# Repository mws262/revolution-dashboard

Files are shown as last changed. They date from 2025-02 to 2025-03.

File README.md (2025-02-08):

A dashboard based on a Lilygo T-Display S3 Touch

 Compatible with VESC firmware 6.02

Dashboard features:
- Show the Battery level and voltage
- Velocity, Trip, ESC and Motor temp
- WiFi connection, OTA programming
- Switching the headlight
- control Rear light & Brake light 
- two driving modes

More information in the Documentation.pdf

Link to 3d printfiles: https://www.thingiverse.com/thing:6682820

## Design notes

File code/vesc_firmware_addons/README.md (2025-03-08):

# Optional adjustments to VESC firmware
My motor controller is an FT85BD. I converted it from using Flipsky's proprietary hardware (see https://github.com/mws262/flipsky-ft85bd-vesc). It has its own MOSFETs for controlling accessories like brake lights and headlight. 

The app_lights VESC application can listen for these commands and switch accordingly. For now, the app is directly started in main.c. In the Rev code, there is a flag, VESC_CONTROLS_LIGHTS, that when set tells the VESC to turn the lights on instead of using ESP32 digital pins to switch the FETs directly.

Note that for the FT85BD, the outputs for the lights are 12V. On the Rev, I believe the lights are 5V. 12V will definitely fry the rear lights. My Rev is missing a bunch of parts, so I don't know about the stock front lights.

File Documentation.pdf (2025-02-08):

# Photo: Levi Jacob Price Rebuilding the Boosted Rev

Documentation

Roland Stollnberger
stollnberger@gmx.at
10.10.2024

Disclaimer
The steps and procedures described in this guide for replacing the electrical components of an e-scooter are intended only for experienced and knowledgeable individuals. Replacing and using modified electrical components can be dangerous and requires a high level of technical understanding and craftsmanship.
Important Notes:
Legal Regulations: Please observe local laws and regulations regarding modifying or the use of modified e-scooters on public roads. Disclaimer: The author of this guide assumes no liability for damages or injuries resulting from the replacement or use of the described electrical components or the provided code. All information is provided without warranty.
Electrical Safety: Handling electrical components can be dangerous. Replacing and using modified electrical components is at your own risk. Ensure that all electrical connections are properly insulated and secured to avoid short circuits and electric shocks.

By using this guide, you agree to the above terms and confirm that you understand the risks.

Unfortunately, a simple battery replacement is not possible with the Rev because the communication between the battery's BMS and the controller has not been cracked yet. The original controller does not start when a retrofit BMS is connected.
To bring the Rev back to live and enhance the range it is necessary to replace the controller, the battery and the dashboard.
There is no plug & play solution. Three main steps are necessary to rebuild the Rev:
- Build a dashboard, in this case with a Lilygo T-Display S3 Touch
- Make a 12s5p Battery
- Buy a VESC based Controller - the Lacroix Stormcore D60+ was used here
(Lacroix went out of business, but there are some alternatives like the VESC HD-60T)

All necessary Files are provided here:
https://github.com/stolliroli/revolution-dashboard

### Step 1 - Dashboard

Part list:
Lilygo T-Display S3 Touch | https://www.lilygo.cc/products/t-display-s3?variant=42589373268149
PCB | https://aisler.net/stolliroli/rolis-projects/revolution-dashboard
| Or use any other fabricator, the files are located in the provided link above.
2x AQV252G PhotoMOS
2x 220 Ohm Resistor, 0805 SMD
1x 1 kOhm Resistor, 0805 SMD
1x 12mm Momentary Switch (short version)
2,54mm JST-XH connector (3x 2Pin, 2x 3Pin, 1x 4Pin) It's best to get a set 3D printed parts (PETG or any other outdoor suitable filament)
Some 2mm screws
2.54mm 2x 12 Pin Female socket Board
Thin wire
4x M3 brass thread inserts

The easiest way to write the code to the Lilygo is using the Arduino IDE.
Following the instruction on Github https://github.com/Xinyuan-LilyGO/T-Display-S3 will help to install the libraries and do the correct settings for the Lilygo display.
Further instructions are in the code “Revolution_Dashboard_1.0.ino” of the shared link.

Once the code is opened in Arduino IDE, there are some settings to check in the Config.h tab (Step 6 – Dashboard config). To program the board later over WIFI it is important to provide your WIFI SSID and Password before installing the Lilygo in the housing. After installation it becomes difficult to connect USB. When the code has been uploaded, next time the Lilygo is connected to USB Power and any of the unlock codes (for driving modes) has been typed in, “WIFI connected” will appear below the battery bar.
Now the port settings have to be changed in Arduino IDE to the IP address of your Lilygo to test the OTA programming.

PCB assembly:

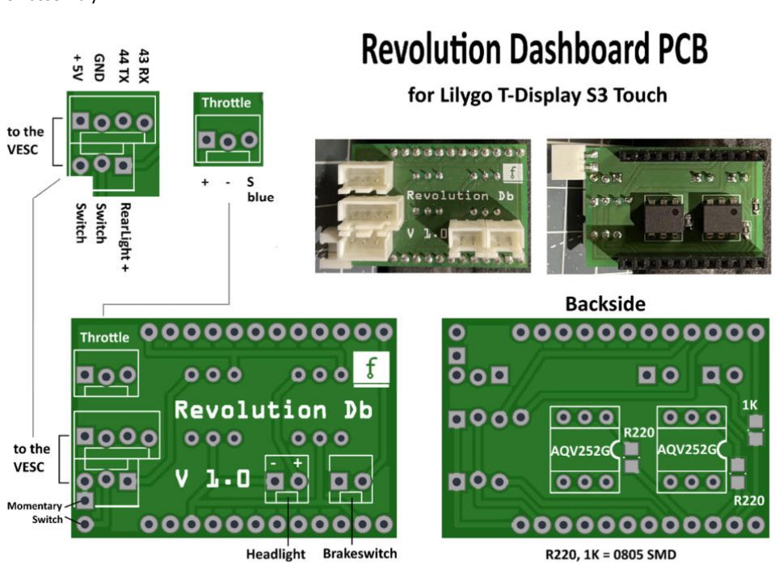
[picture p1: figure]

Before assembly, the housing can be coated with matt clear varnish to make it waterproof.

The Lilygo display is attached with the bracket and two 2mm flat head screws. None of the SMD components should get pinched (If the Lilygo board layout has been changed). Now the PCB can be attached to the Lilygo Display.

Note the following steps if you want to seal the display.
I used “Kafuter K-586 Black Silicone Free Gasket” to seal the display.
First, cover the display with thin plastic packaging tape and insert it into the housing.
Using a craft knife to careful cut along the display recess in the housing. Don't worry, the display glass is so hard and won't get any scratches.
Remove the display again and peel off the tape around the display.
Also cover the housing with the packaging tape and carefully cut out the recess for the display.
Apply the sealant to the inside edge where the display will later rest.
After attaching the display, excess sealing can be wiped off and the packaging tape removed. Allow the seal to cure overnight.

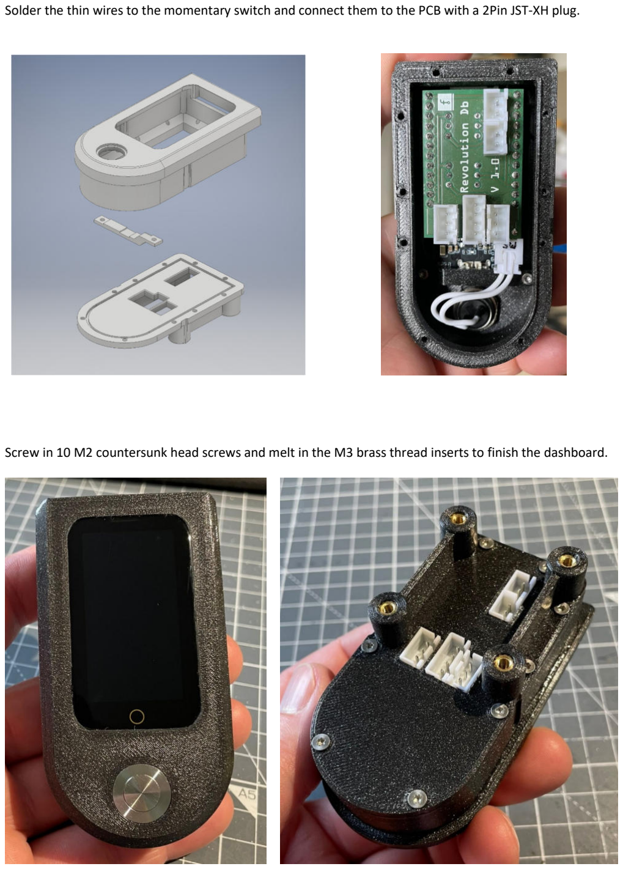
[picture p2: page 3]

Solder the thin wires to the momentary switch and connect them to the PCB with a 2Pin JST-XH plug.

Screw in 10 M2 countersunk head screws and melt in the M3 brass thread inserts to finish the dashboard.

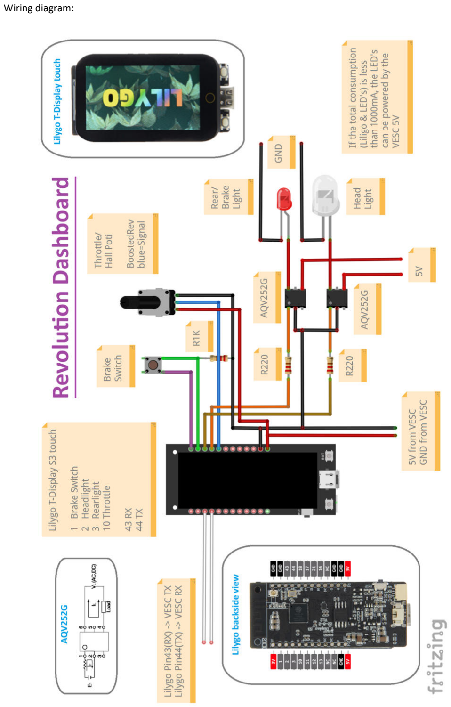
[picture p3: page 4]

Wiring diagram:

### Step 2 - Battery build

Part list:
60x INR21700-P42A https://www.nkon.nl/de/molicel-21700a-4200mah-30a.html JBD Bluetooth Smart BMS 10S-17S 50A
| https://www.aliexpress.com/item/1005005997653586.html?spm=a2g0o.order_list.
| order_list_main.67.34b61802zEt qc9
pure nickel strips (take a look at the chart below)

### 10 AWG Silicon Wire red/black ~30cm (main cable) 16 AWG Silicon Wire red/black ~1m (charging cable) 14 AWG Silicon Wire ~12cm (bus bar)

XT90 female connector (to Stormcore)
XT30 connector pair (charging cable)
60x Cell insulator rings (gasket paper) for 21700 cells Battery Insulation Gasket Barley Paper
Kapton tape 50mm
Shrink tube 180mm x 1m

Keep in mind that your new setup will draw up to 40-50 Ampere. But not all spot welders are able to weld 0.3mm nickel stripes. Multiply the amperage in the table by the number of cells connected in parallel to determine your requirements. Example: 9,6A (0,2mm) x 5 (Cells) = 48A
You can use wider stripes as well. It depends on what you want to do with your Rev.
My measurement was max. 40 Amps on the original Rev ESC.

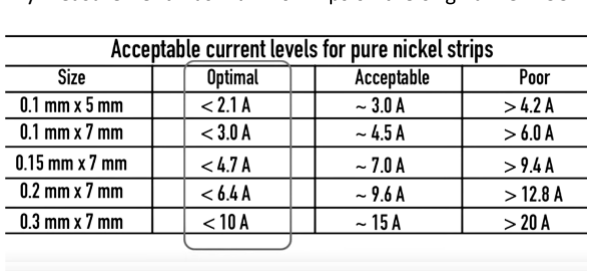
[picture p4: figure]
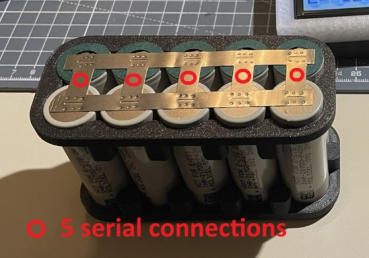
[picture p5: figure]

In order to build a good battery, it is important to test the cells. Faulty cells affect battery performance and lifespan. Many tests can take a lot of time. You should at least check the internal resistance of the individual cells. Outliers should be eliminated. The YR1035+ would be a good choice for this task. Furthermore, it is very important that the cells have the same voltage before welding the cells in parallel to avoid excessive compensating currents.
Calculation: Ampere = V diff / (mOhm/1000). 1-2 A will be OK.
For balancing the cells you need a charger. My V diff was below 0,01V.

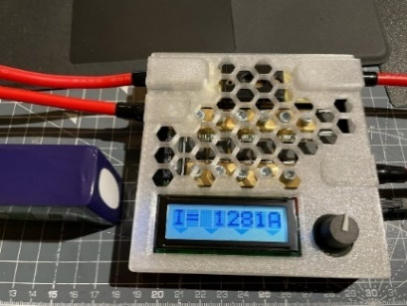
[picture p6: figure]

After a lot of research, I decided on the kWeld spot welder. It draws 1280 Ampere per weld.
This thing rocks.
https://www.keenlab.de/index.php/product/kweld-complete-kit/

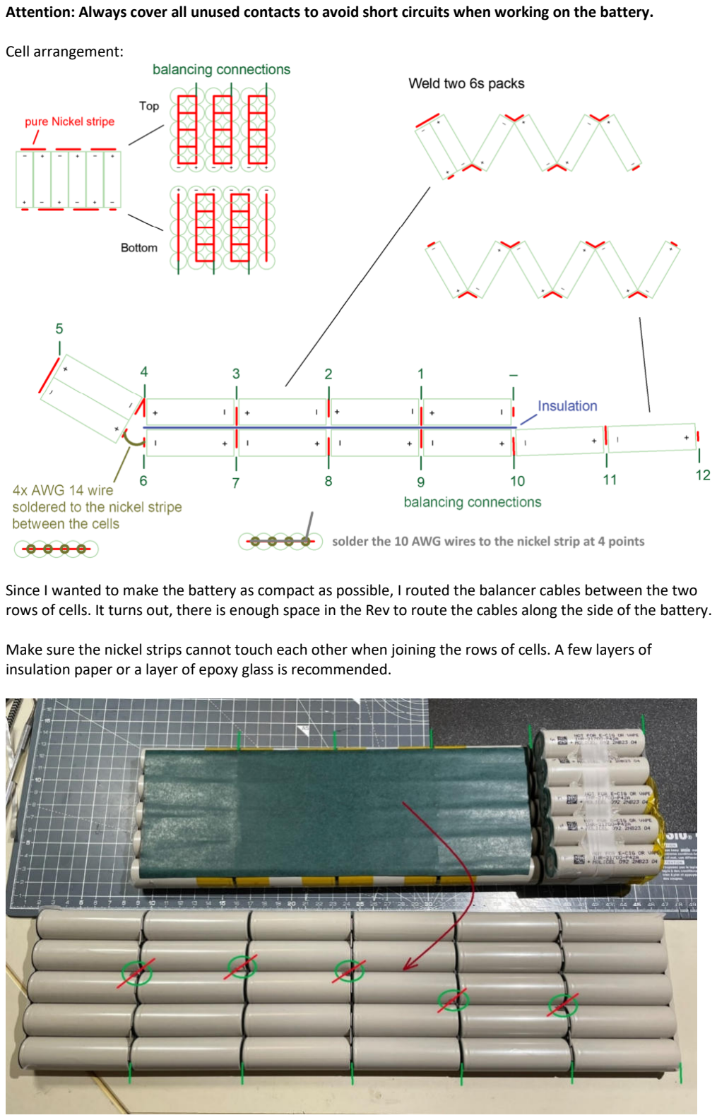
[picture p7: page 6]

Attention: Always cover all unused contacts to avoid short circuits when working on the battery.

Cell arrangement:

Since I wanted to make the battery as compact as possible, I routed the balancer cables between the two rows of cells. It turns out, there is enough space in the Rev to route the cables along the side of the battery.

Make sure the nickel strips cannot touch each other when joining the rows of cells. A few layers of insulation paper or a layer of epoxy glass is recommended.

Remove the plug from the BMS first to solder the BMS cables to the battery. This must be connected later.

The BMS can handle 17 cells in serial. Since we are building a 12s battery, the balancer cables 11-16 must be connected together to the battery connection 11. The 17th cable is connected to cell 12.

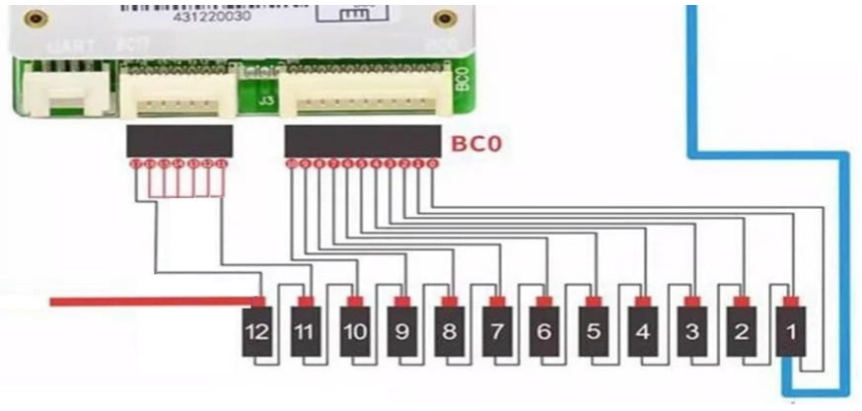
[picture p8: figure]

Building this battery is a bit difficult because the floor inside the Rev is not flat.
To avoid puncturing the battery, I glued foam rubber to important places. Make sure that the battery does not press on the screws of the skid plates.

Before wrapping the battery in insulation paper, I taped off all the contacts and placed the battery in the Rev to measure the angles of the bends. To do this I used a small electronic protractor. Then I recreated the angles on the workbench using wedges. Once the insulation paper is glued to the battery (start with the side walls first), the shape is maintained and the battery should fit into the Rev.

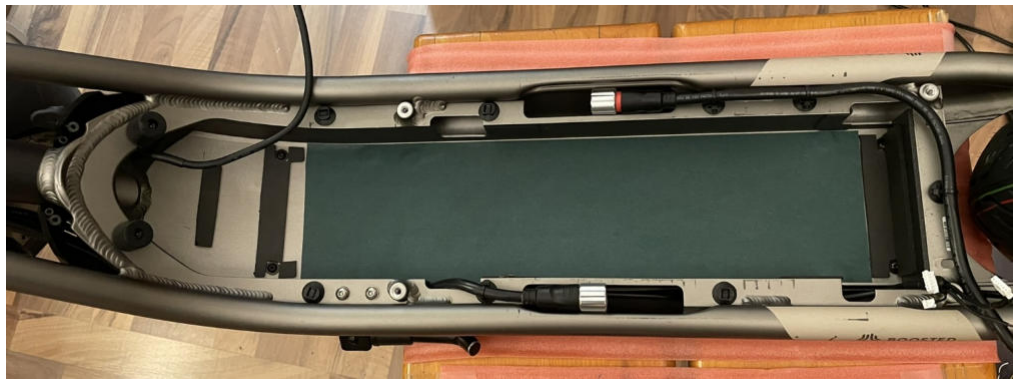
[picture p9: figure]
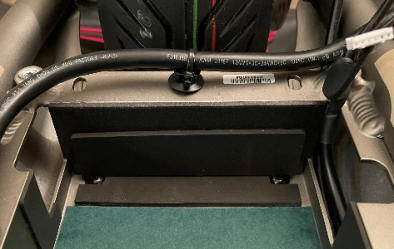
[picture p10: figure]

My Rev doesn't need to be waterproof, but I wanted to keep most of the dust out. That's why I used a 3D printed plate at the back and closed the holes at the floor.
Later I closed the front and rear openings of the side channels with foam rubber.

The BMS has been attached with double-sided adhesive tape to the battery. To avoid heat problems, it is recommended to insert a sheet of epoxy glass in between. Connect the main cables and the charging cable and also the temperature sensors. The final step is to connect the BMS cables and setup the BMS.
Attach the shrink tubing.

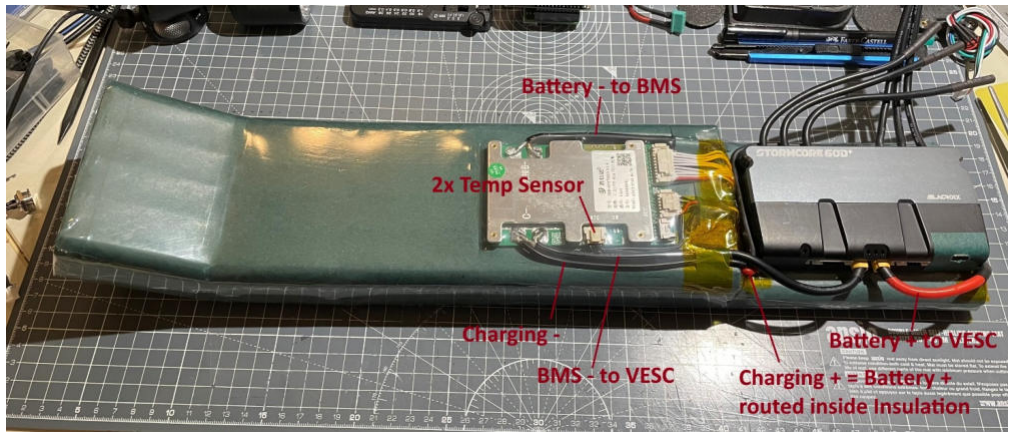
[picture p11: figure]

I taped the ESC on top of the lower cell-row. The ESC could reach higher temperature. A sheet of epoxy glass and thicker double-sided tape is recommended to get a bit of air circulation.

### Step 3 – Setup the BMS

The output and charging function were turned off as default at my JBD BMS. To setup the BMS download the smartphone app. There will be a recommendation from the seller for the associated app to use.
In my case I installed the XiaoXiang iOS app.
You must create a user account to have fully access to the software. Otherwise you can only view data but not change any settings.

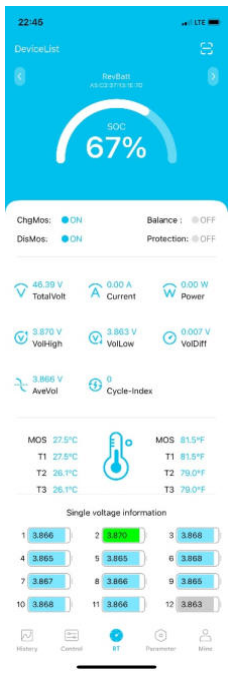
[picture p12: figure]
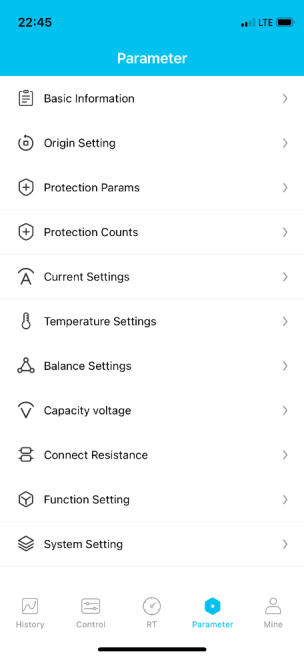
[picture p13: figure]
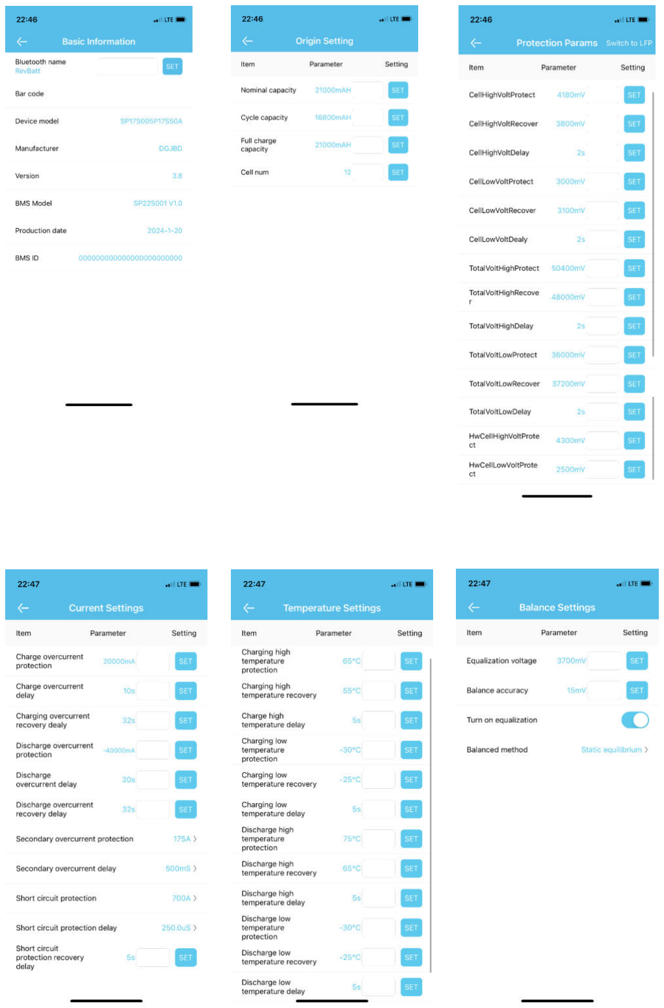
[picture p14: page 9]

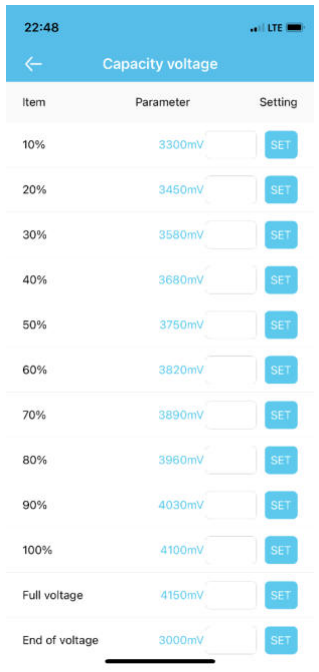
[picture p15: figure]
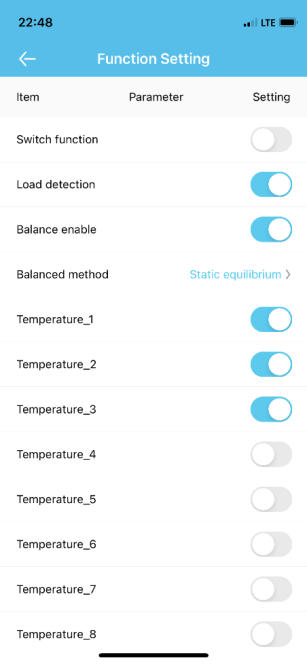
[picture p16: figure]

The BMS should show 12 cells if it is connected correctly to the battery.
Take care about the protection parameters.

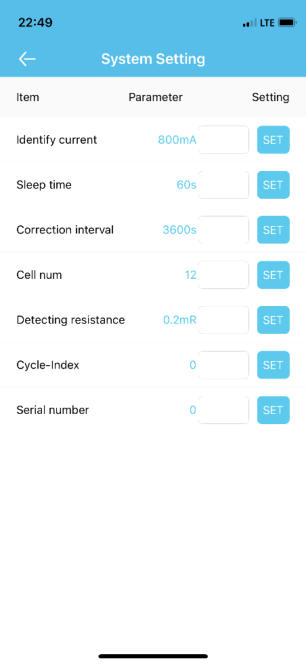
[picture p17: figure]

Unfortunately I couldn't find any instructions for this specific BMS. In the instructions for a similar BMS, at least the principle is well explained: https://macsbatteries.com/images/bms_manuals/Xiaoxiang_BMS_Manual-20220714.pdf

### Step 4 – put it together

Part list:
VESC based Controller
Cable 24AWG, 7Cores, 2m
2,54mm JST-XH connector (3x 2Pin, 2x 3Pin, 1x 4Pin)
2.00mm JST-PH connector (for connecting the Stormcore, other ESC may have other connectors) 6x 4mm Gold Bullet Connector Female
XT30 connector pair (charging cable)

To strip out the original Data cable, gently pull out the two rubber sealings on the steering stem. Build a new Data cable from the Dashboard to the VESC and put it into
the stem.
Ad one 3 Pin and one 4 Pin JST-XH Plug to the cable to connect the
dashboard.

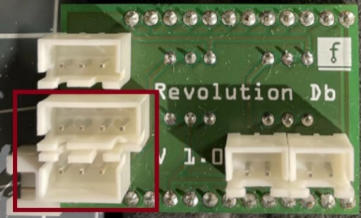
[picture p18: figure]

Connection diagram Stormcore D60+

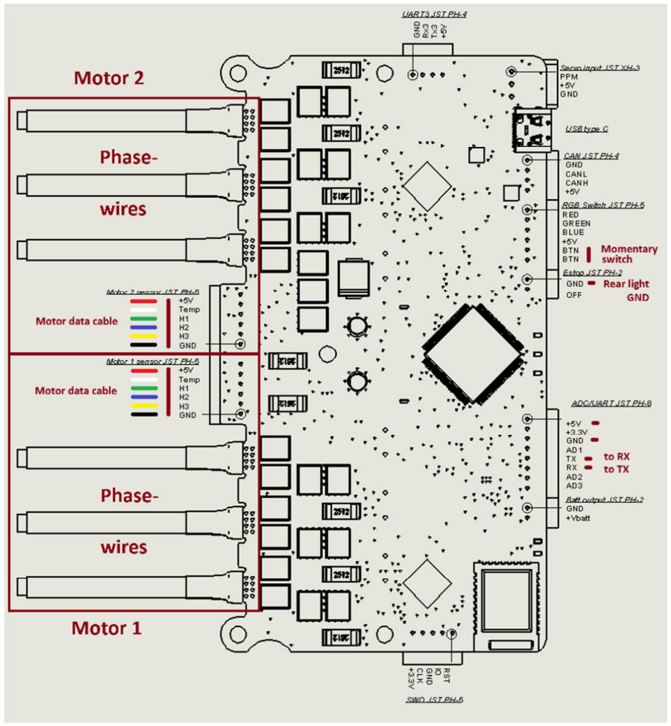
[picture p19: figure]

Route the new cable in the side channel till the end of the battery compartment. Cut it for your needs and crimp the wires as shown in the VESC connection diagram. Use the widest connectors as possible from your set to fit well. Use the + Rear light wire from the dashboard cable and the GND from the esc to connect the Rear light.

Cut the Motor Wires from the original Rev ESC and determine the appropriate length you need.
Solder the Gold Connectors to the thick wires and crimp the JST-PH plugs to the motor data cables. Always add shrink tubes to all connectors. Never leave a cable unprotected!
There is no order for connecting the motor phase wires. The VESC will detect it when running the initialization.
Do not change the connection order after the VESC motor setup. Otherwise you have to repeat this.

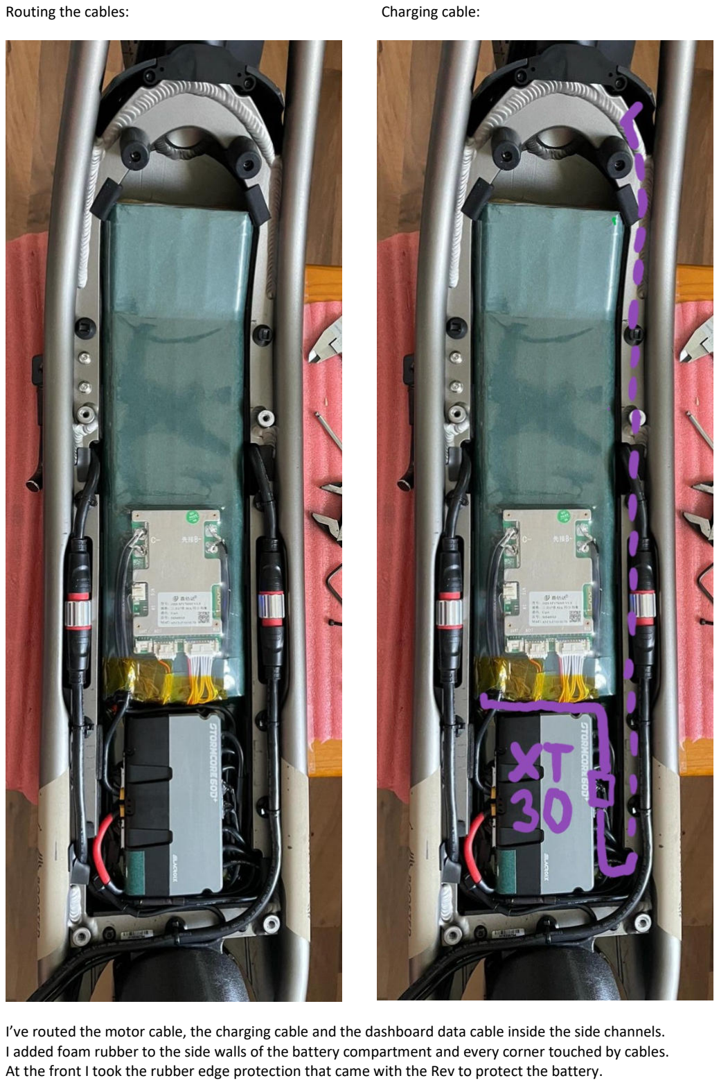
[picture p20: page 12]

Routing the cables: | Charging cable:

I’ve routed the motor cable, the charging cable and the dashboard data cable inside the side channels. I added foam rubber to the side walls of the battery compartment and every corner touched by cables. At the front I took the rubber edge protection that came with the Rev to protect the battery.

### Step 5 – Setup the VESC (Stormcore)

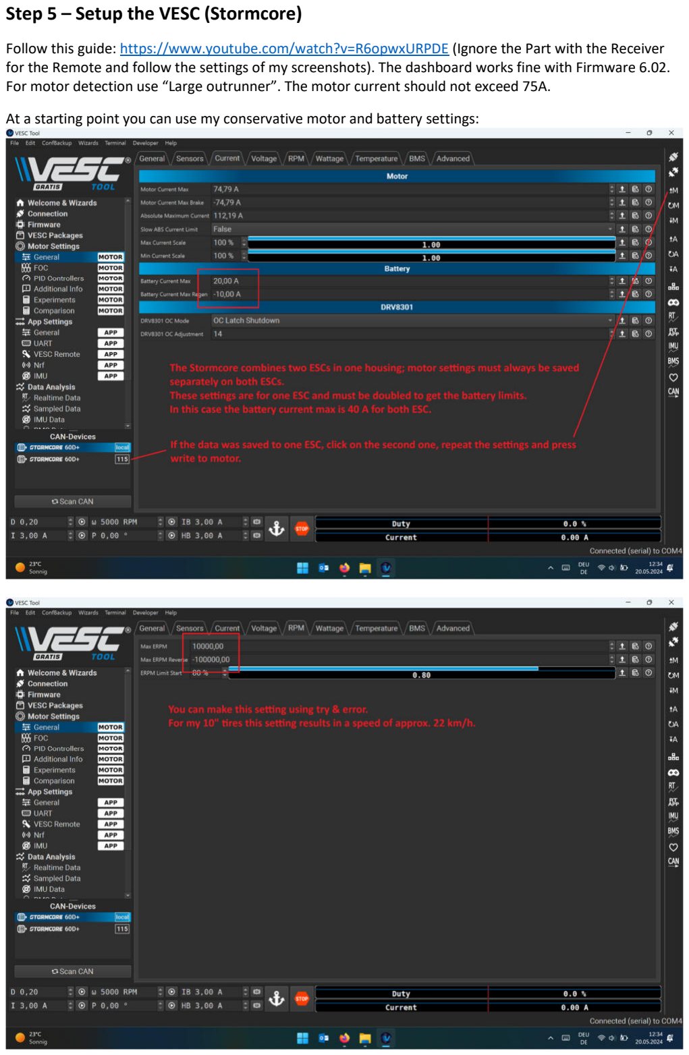
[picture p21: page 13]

Follow this guide: https://www.youtube.com/watch?v=R6opwxURPDE (Ignore the Part with the Receiver for the Remote and follow the settings of my screenshots). The dashboard works fine with Firmware 6.02. For motor detection use “Large outrunner”. The motor current should not exceed 75A.

At a starting point you can use my conservative motor and battery settings:

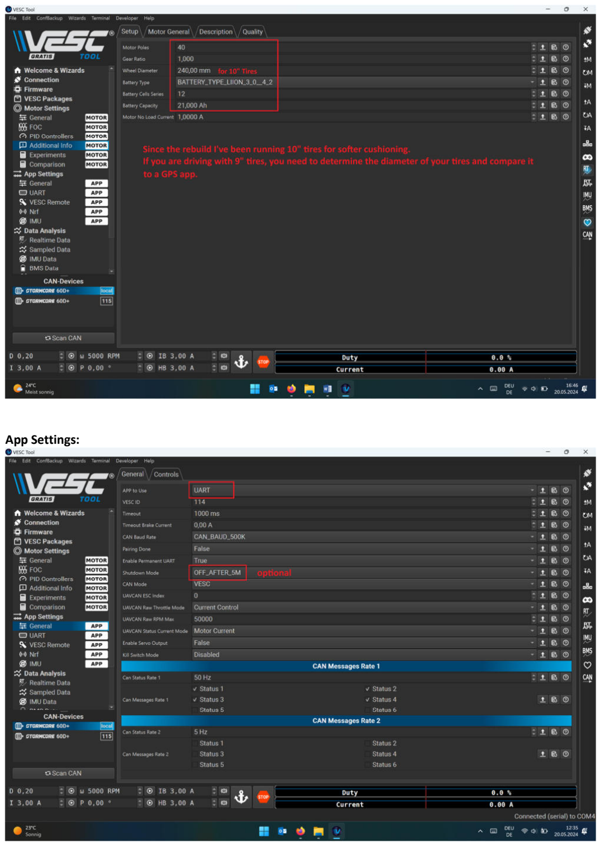
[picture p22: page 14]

App Settings:

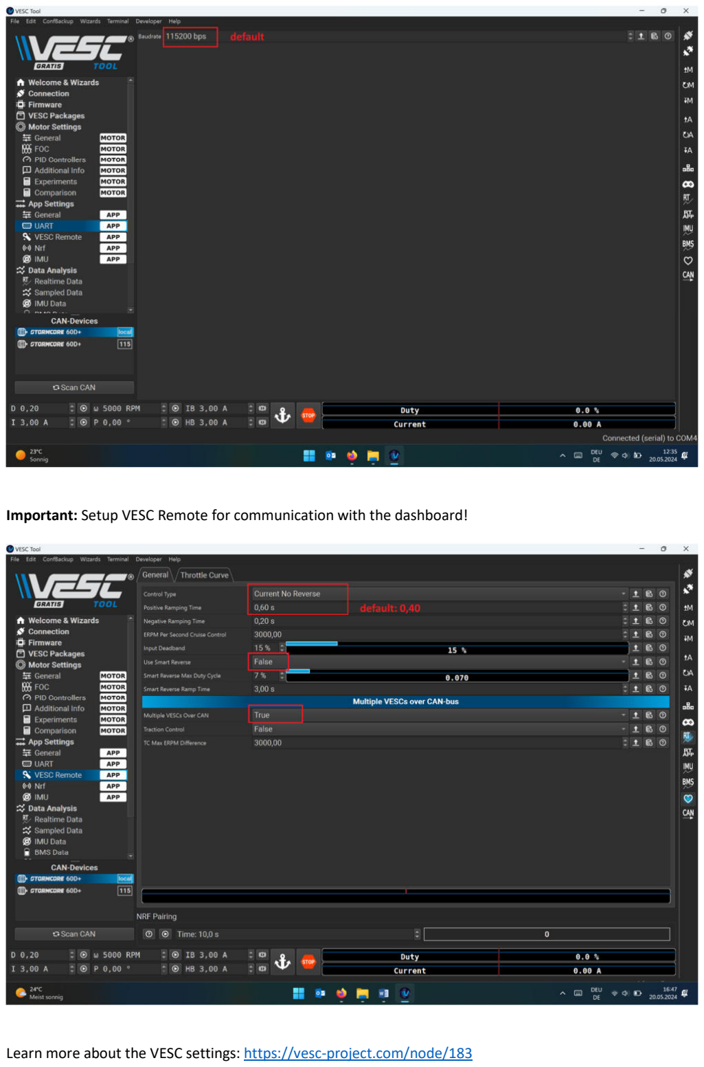
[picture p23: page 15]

Important: Setup VESC Remote for communication with the dashboard!

Learn more about the VESC settings: https://vesc-project.com/node/183

### Step 6 – Dashboard configuration

Take your time to adjust the settings in the cofig.h tab. Most things are simple.

In order to create a somewhat street legal profile, the thPercentage maps the mechanical gas path from zero to the entered value. This function is intended for mode 1 to make the throttle response less aggressive. The value must be adjusted to its own needs. The smaller the value, the smoother the acceleration, but also the power is reduced (problem for steep hills). With a value of 100, the throttle path is passed on to the VESC linearly from 0-100% (as in mode 2).
The max speed for mode 1 has to be set independently in the VESC Tool -> Motor Settings – General - RPM. You could alternatively leave thPercentage at 100% and also reduce the watts in VESC Tool.
(The settings for RPM and Watt will be temporary overwritten when activate mode 2).

I haven't found out if you can set imperial units in the VESC tool. With setMi, the speedometer and trip are switched to miles. I think the mobile app will work this way too. It gets the metric values from the VESC and converts it to imperial units.

tachComp: In theory, with the correct wheel diameter, the speedometer and trip should be displayed correctly. With this multiplier you can also set the trip value exactly on a case-by-case basis.

voltdropcomp: Due to the thin cables from the VESC to the dashboard, a voltage drop of approx. 0.3V occurs when the headlight is switched on. This can hardly be avoided as considerably thicker cables would have to be used. Unfortunately, the output value of the Hall sensor on the throttle lever reacts very sensitively to changes in voltage, so that the min-neutral-max value shifts.
With showThReading the RAW value of the throttle can be read. This is shown on the display above the text Trip. With the throttle in neutral you can see the difference when the light turns on and off. This difference can be compensated with the variable thComp and will be added to the RAW Value when the light is switched on.

I can't remember whether the original REV cuts out engine power when pulling the brake lever. With stopOnBrake you can decide if you want to use this function.

To program the dashboard over WiFi, one of the mode 1 or 2 unlock codes must be entered.

Dashboard features:

- Show the Battery level and voltage
- Velocity, Trip, ESC and Motor temp
- Shows if the WiFi is connected, the Headlight is turned on and mode S is activated
- Turn the headlight on and off
- Calibrate the throttle lever
- Always on Rear light / shines brighter when braking
- Two driving modes (is activated with different unlock codes)

Calibrate the throttle lever first:
Turn on the Rev with a short press to the momentary switch.
Enter the code “1000” and follow the instructions on the display. Press OK to save the throttle values permanently. The dashboard restarts.

How does setting profiles work:

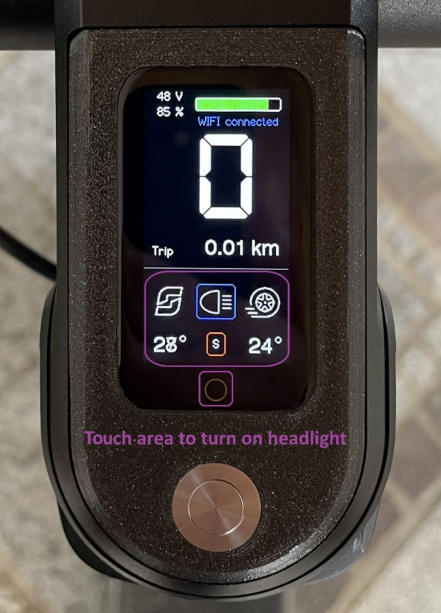
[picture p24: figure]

Profiles are not saved in the VESC, some values are temporarily transferred to the VESC (until restart). In this code the max RPM will be raised in sport mode only.
The smoother acceleration in Mode 1 is achieved by reducing the max throttle value in the Arduino code.

### Step 7 – Test ride

Type in the code for Mode 1 and test all functions.
Take an easy test drive.
When everything goes well, shutdown the Rev by pressing the momentary switch 4 seconds. Power it on again and test Mode 2 (aka Sport Mode).

# Long live the Rev

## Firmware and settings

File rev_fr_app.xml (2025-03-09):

<?xml version="1.0" encoding="UTF-8"?>
<APPConfiguration>
    <ConfigVersion>3</ConfigVersion>
    <controller_id>114</controller_id>
    <timeout_msec>1000</timeout_msec>
    <timeout_brake_current>0</timeout_brake_current>
    <can_status_rate_1>50</can_status_rate_1>
    <can_status_rate_2>5</can_status_rate_2>
    <can_status_msgs_r1>15</can_status_msgs_r1>
    <can_status_msgs_r2>0</can_status_msgs_r2>
    <can_baud_rate>2</can_baud_rate>
    <pairing_done>0</pairing_done>
    <permanent_uart_enabled>1</permanent_uart_enabled>
    <shutdown_mode>7</shutdown_mode>
    <can_mode>0</can_mode>
    <uavcan_esc_index>0</uavcan_esc_index>
    <uavcan_raw_mode>0</uavcan_raw_mode>
    <uavcan_raw_rpm_max>50000</uavcan_raw_rpm_max>
    <uavcan_status_current_mode>0</uavcan_status_current_mode>
    <servo_out_enable>0</servo_out_enable>
    <kill_sw_mode>0</kill_sw_mode>
    <app_to_use>3</app_to_use>
    <app_ppm_conf.ctrl_type>0</app_ppm_conf.ctrl_type>
    <app_ppm_conf.pid_max_erpm>15000</app_ppm_conf.pid_max_erpm>
    <app_ppm_conf.hyst>0.15</app_ppm_conf.hyst>
    <app_ppm_conf.pulse_start>1</app_ppm_conf.pulse_start>
    <app_ppm_conf.pulse_end>2</app_ppm_conf.pulse_end>
    <app_ppm_conf.pulse_center>1.5</app_ppm_conf.pulse_center>
    <app_ppm_conf.median_filter>1</app_ppm_conf.median_filter>
    <app_ppm_conf.safe_start>1</app_ppm_conf.safe_start>
    <app_ppm_conf.throttle_exp>0</app_ppm_conf.throttle_exp>
    <app_ppm_conf.throttle_exp_brake>0</app_ppm_conf.throttle_exp_brake>
    <app_ppm_conf.throttle_exp_mode>2</app_ppm_conf.throttle_exp_mode>
    <app_ppm_conf.ramp_time_pos>0.4</app_ppm_conf.ramp_time_pos>
    <app_ppm_conf.ramp_time_neg>0.2</app_ppm_conf.ramp_time_neg>
    <app_ppm_conf.multi_esc>1</app_ppm_conf.multi_esc>
    <app_ppm_conf.tc>0</app_ppm_conf.tc>
    <app_ppm_conf.tc_max_diff>3000</app_ppm_conf.tc_max_diff>
    <app_ppm_conf.max_erpm_for_dir>4000</app_ppm_conf.max_erpm_for_dir>
    <app_ppm_conf.smart_rev_max_duty>0.07</app_ppm_conf.smart_rev_max_duty>
    <app_ppm_conf.smart_rev_ramp_time>3</app_ppm_conf.smart_rev_ramp_time>
    <app_adc_conf.ctrl_type>2</app_adc_conf.ctrl_type>
    <app_adc_conf.hyst>0.15</app_adc_conf.hyst>
    <app_adc_conf.voltage_start>0.9</app_adc_conf.voltage_start>
    <app_adc_conf.voltage_end>3</app_adc_conf.voltage_end>
    <app_adc_conf.voltage_min>0</app_adc_conf.voltage_min>
    <app_adc_conf.voltage_max>3.5</app_adc_conf.voltage_max>
    <app_adc_conf.voltage_center>2</app_adc_conf.voltage_center>
    <app_adc_conf.voltage2_start>0.9</app_adc_conf.voltage2_start>
    <app_adc_conf.voltage2_end>3</app_adc_conf.voltage2_end>
    <app_adc_conf.use_filter>1</app_adc_conf.use_filter>
    <app_adc_conf.safe_start>1</app_adc_conf.safe_start>
    <app_adc_conf.buttons>0</app_adc_conf.buttons>
    <app_adc_conf.voltage_inverted>0</app_adc_conf.voltage_inverted>
    <app_adc_conf.voltage2_inverted>0</app_adc_conf.voltage2_inverted>
    <app_adc_conf.throttle_exp>0</app_adc_conf.throttle_exp>
    <app_adc_conf.throttle_exp_brake>0</app_adc_conf.throttle_exp_brake>
    <app_adc_conf.throttle_exp_mode>2</app_adc_conf.throttle_exp_mode>
    <app_adc_conf.ramp_time_pos>0.3</app_adc_conf.ramp_time_pos>
    <app_adc_conf.ramp_time_neg>0.1</app_adc_conf.ramp_time_neg>
    <app_adc_conf.multi_esc>1</app_adc_conf.multi_esc>
    <app_adc_conf.tc>0</app_adc_conf.tc>
    <app_adc_conf.tc_max_diff>3000</app_adc_conf.tc_max_diff>
    <app_adc_conf.update_rate_hz>500</app_adc_conf.update_rate_hz>
    <app_uart_baudrate>115200</app_uart_baudrate>
    <app_chuk_conf.ctrl_type>2</app_chuk_conf.ctrl_type>
    <app_chuk_conf.hyst>0.15</app_chuk_conf.hyst>
    <app_chuk_conf.ramp_time_pos>0.4</app_chuk_conf.ramp_time_pos>
    <app_chuk_conf.ramp_time_neg>0.2</app_chuk_conf.ramp_time_neg>
    <app_chuk_conf.stick_erpm_per_s_in_cc>3000</app_chuk_conf.stick_erpm_per_s_in_cc>
    <app_chuk_conf.throttle_exp>0</app_chuk_conf.throttle_exp>
    <app_chuk_conf.throttle_exp_brake>0</app_chuk_conf.throttle_exp_brake>
    <app_chuk_conf.throttle_exp_mode>2</app_chuk_conf.throttle_exp_mode>
    <app_chuk_conf.multi_esc>1</app_chuk_conf.multi_esc>
    <app_chuk_conf.tc>1</app_chuk_conf.tc>
    <app_chuk_conf.tc_max_diff>3000</app_chuk_conf.tc_max_diff>
    <app_chuk_conf.use_smart_rev>0</app_chuk_conf.use_smart_rev>
    <app_chuk_conf.smart_rev_max_duty>0</app_chuk_conf.smart_rev_max_duty>
    <app_chuk_conf.smart_rev_ramp_time>3</app_chuk_conf.smart_rev_ramp_time>
    <app_nrf_conf.speed>1</app_nrf_conf.speed>
    <app_nrf_conf.power>3</app_nrf_conf.power>
    <app_nrf_conf.crc_type>1</app_nrf_conf.crc_type>
    <app_nrf_conf.retry_delay>0</app_nrf_conf.retry_delay>
    <app_nrf_conf.retries>3</app_nrf_conf.retries>
    <app_nrf_conf.channel>76</app_nrf_conf.channel>
    <app_nrf_conf.address__0>198</app_nrf_conf.address__0>
    <app_nrf_conf.address__1>199</app_nrf_conf.address__1>
    <app_nrf_conf.address__2>0</app_nrf_conf.address__2>
    <app_nrf_conf.send_crc_ack>1</app_nrf_conf.send_crc_ack>
    <app_balance_conf.pid_mode>0</app_balance_conf.pid_mode>
    <app_balance_conf.kp>0</app_balance_conf.kp>
    <app_balance_conf.ki>0</app_balance_conf.ki>
    <app_balance_conf.kd>0</app_balance_conf.kd>
    <app_balance_conf.kp2>0</app_balance_conf.kp2>
    <app_balance_conf.ki2>0</app_balance_conf.ki2>
    <app_balance_conf.kd2>0</app_balance_conf.kd2>
    <app_balance_conf.hertz>1000</app_balance_conf.hertz>
    <app_balance_conf.loop_time_filter>0</app_balance_conf.loop_time_filter>
    <app_balance_conf.fault_pitch>20</app_balance_conf.fault_pitch>
    <app_balance_conf.fault_roll>45</app_balance_conf.fault_roll>
    <app_balance_conf.fault_duty>0.9</app_balance_conf.fault_duty>
    <app_balance_conf.fault_adc1>0</app_balance_conf.fault_adc1>
    <app_balance_conf.fault_adc2>0</app_balance_conf.fault_adc2>
    <app_balance_conf.fault_delay_pitch>0</app_balance_conf.fault_delay_pitch>
    <app_balance_conf.fault_delay_roll>0</app_balance_conf.fault_delay_roll>
    <app_balance_conf.fault_delay_duty>0</app_balance_conf.fault_delay_duty>
    <app_balance_conf.fault_delay_switch_half>0</app_balance_conf.fault_delay_switch_half>
    <app_balance_conf.fault_delay_switch_full>0</app_balance_conf.fault_delay_switch_full>
    <app_balance_conf.fault_adc_half_erpm>1000</app_balance_conf.fault_adc_half_erpm>
    <app_balance_conf.fault_is_dual_switch>0</app_balance_conf.fault_is_dual_switch>
    <app_balance_conf.tiltback_duty_angle>10</app_balance_conf.tiltback_duty_angle>
    <app_balance_conf.tiltback_duty_speed>3</app_balance_conf.tiltback_duty_speed>
    <app_balance_conf.tiltback_duty>0.75</app_balance_conf.tiltback_duty>
    <app_balance_conf.tiltback_hv_angle>10</app_balance_conf.tiltback_hv_angle>
    <app_balance_conf.tiltback_hv_speed>3</app_balance_conf.tiltback_hv_speed>
    <app_balance_conf.tiltback_hv>200</app_balance_conf.tiltback_hv>
    <app_balance_conf.tiltback_lv_angle>10</app_balance_conf.tiltback_lv_angle>
    <app_balance_conf.tiltback_lv_speed>3</app_balance_conf.tiltback_lv_speed>
    <app_balance_conf.tiltback_lv>0</app_balance_conf.tiltback_lv>
    <app_balance_conf.tiltback_return_speed>2</app_balance_conf.tiltback_return_speed>
    <app_balance_conf.tiltback_constant>0</app_balance_conf.tiltback_constant>
    <app_balance_conf.tiltback_constant_erpm>500</app_balance_conf.tiltback_constant_erpm>
    <app_balance_conf.tiltback_variable>0</app_balance_conf.tiltback_variable>
    <app_balance_conf.tiltback_variable_max>0</app_balance_conf.tiltback_variable_max>
    <app_balance_conf.noseangling_speed>3</app_balance_conf.noseangling_speed>
    <app_balance_conf.startup_pitch_tolerance>20</app_balance_conf.startup_pitch_tolerance>
    <app_balance_conf.startup_roll_tolerance>8</app_balance_conf.startup_roll_tolerance>
    <app_balance_conf.startup_speed>30</app_balance_conf.startup_speed>
    <app_balance_conf.deadzone>0</app_balance_conf.deadzone>
    <app_balance_conf.multi_esc>0</app_balance_conf.multi_esc>
    <app_balance_conf.yaw_kp>0</app_balance_conf.yaw_kp>
    <app_balance_conf.yaw_ki>0</app_balance_conf.yaw_ki>
    <app_balance_conf.yaw_kd>0</app_balance_conf.yaw_kd>
    <app_balance_conf.roll_steer_kp>0</app_balance_conf.roll_steer_kp>
    <app_balance_conf.roll_steer_erpm_kp>0</app_balance_conf.roll_steer_erpm_kp>
    <app_balance_conf.brake_current>0</app_balance_conf.brake_current>
    <app_balance_conf.brake_timeout>10</app_balance_conf.brake_timeout>
    <app_balance_conf.yaw_current_clamp>0</app_balance_conf.yaw_current_clamp>
    <app_balance_conf.ki_limit>0</app_balance_conf.ki_limit>
    <app_balance_conf.kd_pt1_lowpass_frequency>0</app_balance_conf.kd_pt1_lowpass_frequency>
    <app_balance_conf.kd_pt1_highpass_frequency>0</app_balance_conf.kd_pt1_highpass_frequency>
    <app_balance_conf.booster_angle>8</app_balance_conf.booster_angle>
    <app_balance_conf.booster_ramp>1</app_balance_conf.booster_ramp>
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

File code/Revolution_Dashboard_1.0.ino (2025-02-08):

/*
Project: Revolution Dashboard 1.0
Author: Roland Stollnberger (stollnberger@gmx.at)
Created: 12.05.2024
Description: Control VESC based ESC, set Profiles, Display Data, Lockscreen, Over The Air programming...

Included Libraries:
https://github.com/stolliroli/VescUart
LipoCheck: https://github.com/Peemouse/SmartRing // modified

Install Boards:
Lilygo T-Display S3 Touch: https://github.com/Xinyuan-LilyGO/T-Display-S3 // follow the README to install
https://github.com/espressif/arduino-esp32

Libraries to install (via Arduino IDE):
https://github.com/fbiego/CST816S
https://github.com/denyssene/SimpleKalmanFilter
https://github.com/Bodmer/TFT_eSPI
*/

#include "Arduino.h"
#include "TFT_eSPI.h"
#include <CST816S.h>  //TouchLib
#include "Wire.h"
#include "driver/ledc.h" //for PWM
#include "VescUart.h"
#include "config.h"
#include "LiPoCheck.h"

#include <WiFi.h>
#include <ESPmDNS.h>
#include <WiFiUdp.h>
#include <ArduinoOTA.h>
const char* ssid = WIFI_SSID;
const char* password = WIFI_PASS;
bool WIFI = 0;

#include <SimpleKalmanFilter.h> //to smooth throttle value
SimpleKalmanFilter thFilter(2, 2, 0.01);

#include <Preferences.h>
Preferences pref;

#include <HardwareSerial.h>
HardwareSerial SerialVESC(2);
VescUart UART;

//images & font
#include "Rev1.h"
#include "Esc.h"
#include "Mot.h"
#include "Light.h"
#include "DSEG7.h"

//setup PWM for rearlight
const int PWM_CHANNEL = 1;
const int PWM_FREQ = 500;
const int PWM_RESOLUTION = 8;
const int backLight_DUTY_CYCLE = dimmBL;
const int brakeLight_DUTY_CYCLE = 255; // 255 for max brightness = brakelight

float erpm = 0;
float rpm = 0;
float speed = 0;
int batt = 0;
int battPerc;
float trip;
int escT = 0;
int motT = 0;
bool profSet = 0;

bool lightF = 0;
bool lock = 1;
bool modeS = 0;
bool confMode = 0;

String entry = "";

int nunck = 127;
uint32_t filterTime = 0; //for Kalman Filter
bool filterDelay = 1;

unsigned int maxVal = analogRead(throttle);
unsigned int minVal = analogRead(throttle);
unsigned int thMax;
unsigned int thZero;
unsigned int thMin;
unsigned int throttleRAW;

//debounce for touch
unsigned long lastTouchTime = 0;  //to manage debounce
unsigned long debounceDelay = 300;  //delay in milliseconds to wait for next valid touch input

TFT_eSPI tft = TFT_eSPI(); 
TFT_eSprite mainSprite= TFT_eSprite(&tft);

void setup() {
 //OTA
 WiFi.mode(WIFI_STA);
 WiFi.begin(ssid, password);
 ArduinoOTA
 .onStart([]() {
   String type;
   if (ArduinoOTA.getCommand() == U_FLASH)
     type = "sketch";
   else // U_SPIFFS
     type = "filesystem";
  });
 ArduinoOTA.begin();
 //data storage
 pref.begin("thValues", true); //"true" defines a read-only access
 thMax = pref.getUInt("thMax", 0);
 thZero = pref.getUInt("thZero", 0);
 thMin = pref.getUInt("thMin", 0);
 pref.end();
 //serial VESC
 SerialVESC.begin(115200, SERIAL_8N1, 43, 44); //Lilygo Pin43=RX to VescTX, Lilygo Pin44=TX to VescRX
 while (!SerialVESC) {;}
 UART.setSerialPort(&SerialVESC);
 UART.getFWversion();
 //setup the input & output pins
 pinMode(headlight, OUTPUT);
 pinMode(brakeSw, INPUT);
 pinMode(throttle, INPUT);
 ledcSetup(PWM_CHANNEL, PWM_FREQ, PWM_RESOLUTION);
 ledcAttachPin(rearlight, PWM_CHANNEL);
 //display
 tft.init();
 tft.setRotation(0);
 tft.setSwapBytes(true);
 tft.pushImage(0,0,170,320,Rev1);
 mainSprite.createSprite(170,320);
 mainSprite.setSwapBytes(true); 
 //touch
 pinMode(PIN_POWER_ON, OUTPUT);
 digitalWrite(PIN_POWER_ON, HIGH);
 touch.begin();

 delay(2500); // waiting to start the VESC
 lockscreen(-1,-1);
}

void lockscreen(int x, int y) {

 tft.fillScreen(TFT_BLACK);
 tft.setTextColor(TFT_WHITE,TFT_BLACK);    
 tft.setTextDatum(4);

 int xpos[3]={3,58,113};
 int ypos[4]={73,128,183,238};
 char chars[4][3]={{'1','2','3'},{'4','5','6'},{'7','8','9'},{' ','0','x'}};
 int sx=10, sy=10;
 for(int i=0;i<4;i++){if(y>=ypos[i] && y<=ypos[i]+54)
 sy=i;
 for(int j=0;j<3;j++){if(x>=xpos[j] && x<=xpos[j]+54)
 sx=j;
 if(sx==j && sy==i)    
  tft.drawRoundRect(xpos[j],ypos[i],54,54,2,TFT_DARKGREY);
 else
  tft.drawRoundRect(xpos[j],ypos[i],54,54,2,TFT_WHITE);  
  tft.drawRoundRect(3,238,54,54,2,TFT_BLACK);
  tft.drawRoundRect(113,238,54,54,2,TFT_BLACK);
  tft.drawString(String(chars[i][j]),xpos[j]+27,ypos[i]+30,4);
 if(x>=xpos[j] && x<=xpos[j]+54)
 sx=j;
 }}
              
 if(chars[sy][sx]=='x') //clear entry
   entry="";
 else
   entry=entry+String(chars[sy][sx]);
   
 if(entry.toInt() == mode1) {
   lock=0;
  }

 if(entry.toInt() == mode2) {
   modeS=1;
   lock=0;
  }

  tft.drawString(entry,85,40,6); //draw touched entry

 if(entry.toInt() == throttleCal) {
   confMode = 1;
  }
}

void drawScreen() {
 //Sprite
 mainSprite.fillSprite(TFT_BLACK);
 mainSprite.unloadFont(); //to draw all other txt before DSEG7 font
 //WIFI connection
 mainSprite.setTextColor(TFT_BLUE,TFT_BLACK);
 mainSprite.setTextDatum(4);
 if (WIFI == 1)
   mainSprite.drawString("WIFI connected",110,37,2);
 //batt bar
 mainSprite.setTextColor(TFT_WHITE,TFT_BLACK);
 if (battPerc>15) {
  mainSprite.fillRoundRect(60,10,battPerc,15,2,TFT_GREEN);
  }
 else {
  mainSprite.fillRoundRect(60,10,battPerc,15,2,TFT_RED);
  }
 mainSprite.drawRoundRect(60,10,100,15,2,TFT_WHITE);
 //batt txt
 mainSprite.drawString(String(batt)+" V",30,8,2);
 mainSprite.drawString(String(battPerc)+" %",30,26,2);
 //trip txt
 mainSprite.setTextDatum(0);
 mainSprite.drawString(String("Trip"),10,182,2);
 mainSprite.setTextDatum(2);
 if (setMi == 1) {
    mainSprite.drawString(String(trip*0.621371,2)+" mi",160,175,4);
 }
 else {
    mainSprite.drawString(String(trip,2)+" km",160,175,4);
 }
 //show throttle reading
 if (showThReading == 1) {
   mainSprite.setTextDatum(0);
   mainSprite.drawString(String(throttleRAW),10,162,2);
 }
 //line
 mainSprite.drawLine(0,210,170,210,TFT_DARKGREY);
 //ESCTemp txt
 mainSprite.setTextDatum(2);
 mainSprite.drawString(String(escT),40,290,4);
 mainSprite.drawCircle(46,293,3,TFT_WHITE);
 mainSprite.pushImage(10,230,40,40,Esc);
 //motTemp txt
 mainSprite.setTextDatum(2);
 mainSprite.drawString(String(motT),152,290,4);
 mainSprite.drawCircle(158,293,3,TFT_WHITE);
 mainSprite.pushImage(120,230,40,40,Mot);
 //mode
 if (modeS==1) {mainSprite.drawRoundRect(75,286,22,27,3,TFT_RED);}
 else {mainSprite.drawRoundRect(75,286,22,27,3,TFT_DARKGREY);}
 mainSprite.setTextDatum(4);
 mainSprite.drawString(String("S"),86,299,2);
 //light
 mainSprite.pushImage(65,230,40,40,Light);
 if (lightF==1) {mainSprite.drawRoundRect(62,229,46,41,3,TFT_BLUE);}
 else {mainSprite.drawRoundRect(62,229,46,41,3,TFT_DARKGREY);}
 //speed
 mainSprite.setTextDatum(4);
 mainSprite.loadFont(DSEG7);
 if (setMi == 1) {speed = speed*0.621371;}
 if (speed < 0) {speed = 0;}
 else {mainSprite.drawString(String(speed,0),79,102,8);}
 //push Sprite to disp
 mainSprite.pushSprite(0,0);
}

void loop() {
 //OTA
 if (WiFi.waitForConnectResult() == WL_CONNECTED) {
   WIFI = 1; }
 else {WIFI = 0;}
 ArduinoOTA.handle();
 
 //Lockscreen
 while (lock==1 && confMode==0) {
    if (touch.available()) {
      unsigned long currentTouchTime = millis();
      if (currentTouchTime - lastTouchTime > debounceDelay) {
        lastTouchTime = currentTouchTime;
        if(touch.data.y > 75 && touch.data.y < 290)
          lockscreen(touch.data.x,touch.data.y);
      }
    }
  }

 // calculate the estimated value with Kalman Filter
 throttleRAW = thFilter.updateEstimate(analogRead(throttle));

 //calibrate throttle
 while (confMode==1) {
    mainSprite.fillSprite(TFT_BLACK);
    mainSprite.setTextColor(TFT_WHITE,TFT_BLACK);
    mainSprite.setTextDatum(4);
    mainSprite.drawString("move throttle",85,20,2);
    mainSprite.drawString("a few times from",85,40,2);
    mainSprite.drawString("full throttle to full brake",85,60,2);
    mainSprite.drawString("and press OK",85,80,2);
    mainSprite.drawRoundRect(10,245,70,50,2,TFT_RED);
    mainSprite.drawString("X",45,272,4);
    mainSprite.drawRoundRect(90,245,70,50,2,TFT_GREEN);
    mainSprite.drawString("OK",125,272,4);

    unsigned int throttleRAW = thFilter.updateEstimate(analogRead(throttle));

    if(throttleRAW > maxVal) {
      maxVal = throttleRAW;
    }

    if(throttleRAW < minVal) {
      minVal = throttleRAW;
    }

    mainSprite.setTextDatum(0);
    mainSprite.drawString("old Value",5,110,2);
    mainSprite.drawString(String(thMax),5,130,4);
    mainSprite.drawString(String(thZero),5,160,4);
    mainSprite.drawString(String(thMin),5,190,4);

    mainSprite.setTextDatum(2);
    mainSprite.drawString("new Value",165,110,2);
    mainSprite.drawString(String(maxVal),165,130,4);
    mainSprite.drawString(String(throttleRAW),165,160,4);
    mainSprite.drawString(String(minVal),165,190,4);

    mainSprite.pushSprite(0,0);

    if (touch.available()) {
      unsigned long currentTouchTime = millis();
      if (currentTouchTime - lastTouchTime > debounceDelay) {
        lastTouchTime = currentTouchTime;
        if(touch.data.y > 245 && touch.data.y < 295 && touch.data.x > 85) {
          pref.begin("thValues", false);
          pref.putUInt("thMax", maxVal); //at 5V input, the Hall Sensor Value schould be 4095 on full throttle
          pref.putUInt("thZero", throttleRAW); //schould be about 2880, depends on input Voltage ~ 5V
          pref.putUInt("thMin", minVal); //schould be about 2100, depends on input Voltage ~ 5V
          pref.end();
          mainSprite.fillSprite(TFT_BLACK);
          mainSprite.pushSprite(0,0);
          delay(100);
          ESP.restart();
        }
        if(touch.data.y > 245 && touch.data.y < 295 && touch.data.x < 85) {
          mainSprite.fillSprite(TFT_BLACK);
          mainSprite.pushSprite(0,0);
          ESP.restart();
        }
      }
    }
  }

 //set profile
 if (modeS == 1 && profSet == 0) {
    bool store = false;                    //save persistently the new profile in vesc memory
    bool forward_can = true;               //forward profile to slave Vesc through can bus
    bool ack = false;
    bool divide_by_controllers = false;     //divied the watt limit by the number of VESC
    float current_min_rel = 1.0;            //this value is multiplied with the minimum current. It is a convenient method to scale the current limits without forgetting the actual minimal value.  DEFAULT = 1
    float current_max_rel = 1.0;            //this value is multiplied with the maximum current. It is a convenient method to scale the current limits without forgetting the actual maximum value.  DEFAULT = 1
    float speed_max_reverse = -15;          //maximum reverse speed in m/s. In order, to use it make sure to set the wheel diameter and gear ratio in VESC Tool   (m/s = (km/h / 3.6) )
    float speed_max = 15;                   //maximum speed in m/s. In order, to use it make sure to set the wheel diameter and gear ratio in VESC Tool
    float duty_min = 0.005;                 //minimum duty cycle. DEFAULT = 0.005
    float duty_max = 1;                     //maximum duty cycle. DEFAULT = 1
    float watt_min = -1500000.0;            //minimum watt value. DEFAULT = - 1500000.0
    float watt_max = 1500000.0 ;            //maximum watt value. DEFAULT =  1500000.0

    UART.setLocalProfile(store, forward_can, divide_by_controllers, current_min_rel, current_max_rel, speed_max_reverse, speed_max, duty_min, duty_max, watt_min, watt_max);
    profSet = 1;
  }

 //switch headlight
 if (touch.available()) {
    unsigned long currentTouchTime = millis();
    if (currentTouchTime - lastTouchTime > debounceDelay) {
      lastTouchTime = currentTouchTime;
//      if(touch.data.x == 85 && touch.data.y == 360) //only the touch button
        if(touch.data.y >= 212)
        lightF =! lightF;     
    }
  }

  if (lightF == HIGH) {
    digitalWrite(headlight, HIGH);
  }
  else {
    digitalWrite(headlight, LOW);
  }

 //handling brakelight
  if (digitalRead(brakeSw) == HIGH || throttleRAW < thZero-250) {  //reduce -250 for brakelight deadband
    ledcWrite(PWM_CHANNEL, brakeLight_DUTY_CYCLE);
  }
  else {
    ledcWrite(PWM_CHANNEL, backLight_DUTY_CYCLE);
  }

 //reading VESC data
 if (UART.getVescValues()) {
    erpm = UART.data.rpm;
    batt = UART.data.inpVoltage;
    escT = UART.data.tempFET;
    motT= UART.data.tempMotor;
    trip = UART.data.tachometer;
  }
 rpm = erpm/motPol;
 speed = erpm/motPol*wheelDia*3.1415*0.00006;
 trip = trip/wheelDia/1000*tachComp;
 battPerc = CapCheckPerc(batt, numbCell);

 //calc nunchuck value
 float maxNunck;
 if (modeS == true) {
   maxNunck = 255;
 }
 else {
   maxNunck = thPercentage*0.01*127+127;
  }

 if (lightF == HIGH && voltdropcomp == 1) {   //compensation of the voltage drop when headlight is turned on
    throttleRAW = throttleRAW + thComp;
  }

 if (throttleRAW > thZero) {
   nunck = map(throttleRAW, thZero, thMax+100, 127,maxNunck); //+100 to avoid running out of range
  }
 else if (throttleRAW < thZero) {
   nunck = map(throttleRAW, thZero, thMin-100, 127,0); //-100 to avoid running out of range
  }

 if (digitalRead(brakeSw) == 1 && nunck > 127 && stopOnBrake == 1) {
   nunck = 127; // interrupts acceleration when braking
  }

 //send nunchuck value to VESC
 if((millis() - filterTime) > 1000 && filterDelay == 1) {  // this delay prevents the motors from stuttering at start when applying the kalman filter
    filterDelay = 0;
    filterTime = millis();
  }
 else {
   UART.nunchuck.valueY = nunck;
   UART.setNunchuckValues();
  }
 drawScreen();
}

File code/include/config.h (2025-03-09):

#ifndef _CONFIG_H_
#define _CONFIG_H_

#include <Arduino.h>
#include <TFT_eSPI.h>

#define PIN_BRAKE_SW 1
#define PIN_HEADLIGHT 2
#define PIN_REARLIGHT 3
#define PIN_THROTTLE 10 // signal from throttle (max 3,3V)

#define PIN_POWER_ON 15
#define PIN_LCD_RES 5
#define PIN_BUTTON_1 0
#define PIN_BUTTON_2 14
#define PIN_BAT_VOLT 4

#define PIN_TOUCH_SDA 18
#define PIN_TOUCH_SCL 17
#define PIN_TOUCH_IRQ 16
#define PIN_TOUCH_RST 21

// #define DRY_RUN_MODE // Will not send motor commands to the vesc. For testing.
#define VESC_CONTROLS_LIGHTS // If the VESC has built-in FETs for controlling lights.
#define WIFI_ENABLED
// #define WIFI_CONSOLE_ENABLED

const bool headlightOnByDefault = false;

// user setup
float thPercentage = 80; // limits max % of throttle for mode1, enter max. RPM in VESC Tool (Motor
                         // Settings - General - RPM)

/*
Driving modes are not saved in the VESC, only some values are temporarily transferred to the
VESC (until restart). In this sketch only the max RPM is increased in sport mode. The smoother
acceleration in mode 1 is achieved by reducing the max throttle value.
*/

// Rear light brightnesses normal and while braking.
const uint8_t BACK_RUNNING_LIGHT_PERCENT = 20;
const uint8_t BACK_BRAKING_LIGHT_PERCENT = 100;

// This values are independent from VESC Tool, you have to set it too.
const float WHEEL_DIA_MM = 240.0f; // tyre Size in mm, tune this to get correct velocity (also set the
                                // same diameter in the VESC Tool)
const uint8_t MOT_POLE_PAIRS = 20; // motor pole pairs (Boosted Rev = 40 magnets)

const uint8_t BATT_SERIES_CELLS = 12; // number of cells in series of the battery pack

constexpr uint32_t TOUCH_DEBOUNCE_TIME_MS = 300; // delay to wait for next valid touch input
constexpr uint32_t ANTI_STUTTER_DELAY_MS = 1000; // throttle delay after mode change

bool useMiles = false; // km/mi toggle

float tachComp = 1.00; // if distance is different to GPS, compensate it with this multiplier

bool voltdropcomp = true;   /* The throttle reading is very sensitive on the given imput voltage.
  The 5V rail drops when turn on the headlight. This depends on the thin and long wires connected from
  the VESC to the dashboard.   1 = Turn on the compensation, this increases the reading of the throttle
  value. */
bool showThReading = false; // Turn this on to have a look at the input reading. This will be
                            // displayed above the text "Trip".
const int16_t thComp = 0; // This should be the difference of the input reading of the throlle if
                            // the headlight is turned on or off.

bool stopOnBrake = true; // 1 = the motors can not accelerate whie using the disc brake, 0 = motors
                         // can accelerate while braking

constexpr float MI_PER_KM = 0.621371f;
constexpr float MIN_PER_HOUR = 60.0f;
constexpr float KM_PER_MM = 1.0f / 1000000.0f;

// GUI settings
constexpr uint16_t BACKGROUND_COLOR = TFT_BLACK;

#endif // _CONFIG_H_

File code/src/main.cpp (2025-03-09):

// /*
// Project: Revolution Dashboard 1.0
// Author: Roland Stollnberger (stollnberger@gmx.at)
// Created: 12.05.2024
// Description: Control VESC based ESC, set Profiles, Display Data, Lockscreen,
// Over The Air programming...

// Included Libraries:
// https://github.com/stolliroli/VescUart
// LipoCheck: https://github.com/Peemouse/SmartRing // modified
//
// Updates from Matt Sheen (matthewsheen@gmail.com)
// */
#define log_printf \
  custom_log_printf  // This lets me override the Arduino logging print function
                     // so I can also send all messages to the webserver.
#include <Arduino.h>
#include <ArduinoOTA.h>
#include <CST816S.h>  //TouchLib
#include <ESPmDNS.h>
#include <HardwareSerial.h>
#include <Preferences.h>
#include <SimpleKalmanFilter.h>  //to smooth throttle value
#include <WiFi.h>
#include <WiFiUdp.h>

#include "LiPoCheck.h"
#include "TFT_eSPI.h"
#include "VescUart.h"
#include "Wire.h"
#include "config.h"
#include "driver/ledc.h"  //for PWM
#include "private_credentials.h"
// images & font
#include "DSEG7.h"
#include "Esc.h"
#include "Light.h"
#include "Mot.h"
#include "Rev1.h"
#include "debug_webserver.hpp"

const char *ssid = WIFI_SSID;
const char *password = WIFI_PASSWORD;

enum class RevMode { LOCK, CALIBRATE, RIDE_NORMAL, RIDE_SPORT };

RevMode currentMode = RevMode::LOCK;

SimpleKalmanFilter thFilter(1, 2, 0.1);
Preferences pref;
HardwareSerial SerialVESC(2);
VescUart vescUart;
CST816S touch(PIN_TOUCH_SDA, PIN_TOUCH_SCL, PIN_TOUCH_RST, PIN_TOUCH_IRQ);

#ifdef WIFI_CONSOLE_ENABLED
DebugWebServer debugServer;
#endif

// setup PWM for rearlight
const uint8_t PWM_CHANNEL = 1;
const uint32_t PWM_FREQ = 500;
const uint8_t PWM_RESOLUTION = 8;

constexpr long TARGET_LOOP_RATE = 8;  // Hz
constexpr long TARGET_LOOP_PERIOD = 1000 / TARGET_LOOP_RATE;
const uint16_t WIFI_RECONNECTION_INTERVAL = 5000;

float erpm = 0;
float rpm = 0;
float speed_kmh = 0;
int batt_voltage = 0;
int battPerc;
float trip;
int escT = 0;
int motT = 0;
float maxNunck;

bool lightF = false;
bool throttleValuesSet =
    false;  // Prevent the Rev from going into one of the drive modes when the
            // throttle calibration values aren't set.

String pin_entry = "";

int nunck = 127;

uint16_t maxVal = analogRead(PIN_THROTTLE);
uint16_t minVal = analogRead(PIN_THROTTLE);
uint16_t thMax;
uint16_t thZero;
uint16_t thMin;
uint16_t throttleRAW;

uint32_t lastTouchTime = 0;  // to manage debounce
uint32_t lastModeChangeTimeMs = 0;
uint32_t lastLoopTime = 0;
uint32_t lastReconnectAttempt = 0;

bool wifiEverConnected = false;

TFT_eSPI tft = TFT_eSPI();
TFT_eSprite cockpitSprite = TFT_eSprite(&tft);
TFT_eSprite lockSprite = TFT_eSprite(&tft);

uint8_t lastBrakeLightBrightness =
    0;  // Track the last value so we don't send the same command repeatedly.

void setVescProfileSport();
void setVescProfileNormal();
void changeMode(RevMode newMode);
bool waitForVescConnection(uint32_t timeout_ms);
int custom_log_printf(const char *format, ...) {
  char log_buf[256];

  // Process variadic arguments
  va_list args;
  va_start(args, format);
  int len = vsnprintf(log_buf, sizeof(log_buf), format, args);
  va_end(args);

  // Print to Serial
  Serial.print(log_buf);

// Send to WebSocket
#ifdef WIFI_CONSOLE_ENABLED
  debugServer.broadcast(String(log_buf));
#endif

  return len;
}

void setup() {
  Serial.begin(115200);
// Initiate wifi for OTA updates. This is non-blocking. The main loop will
// handle other initializations once the network is connected.
#ifdef WIFI_ENABLED
  log_d("Connecting to WiFi...");
  WiFi.mode(WIFI_STA);
  WiFi.begin(ssid, password);
#endif

  // data storage
  log_d("Loading preferences...");
  pref.begin("thValues", false);  // "true" defines read-only access
  thMax = pref.getUInt("thMax", UINT32_MAX);
  thZero = pref.getUInt("thZero", UINT32_MAX);
  thMin = pref.getUInt("thMin", UINT32_MAX);
  pref.end();

  // If throttle values aren't set, keep the rev from going into a drive mode.
  if (thMax == UINT32_MAX || thZero == UINT32_MAX || thMin == UINT32_MAX) {
    log_w("Throttle values not found in preferences. Using defaults.");
  } else {
    throttleValuesSet = true;
  }

  // serial VESC
  log_d("Setting up serial VESC...");
  SerialVESC.begin(115200, SERIAL_8N1, 43,
                   44);  // Lilygo Pin43=RX to VescTX, Lilygo Pin44=TX to VescRX
  while (!SerialVESC) {
  }
  vescUart.setSerialPort(&SerialVESC);

  pinMode(PIN_BRAKE_SW, INPUT);
  pinMode(PIN_THROTTLE, INPUT);

  // display
  log_d("Setting up display...");
  tft.init();
  tft.setRotation(0);
  tft.setSwapBytes(true);
  tft.pushImage(0, 0, TFT_WIDTH, TFT_HEIGHT, Rev1);
  cockpitSprite.createSprite(TFT_WIDTH, TFT_HEIGHT);
  cockpitSprite.setSwapBytes(true);
  lockSprite.createSprite(TFT_WIDTH, TFT_HEIGHT);
  lockSprite.setSwapBytes(true);

  // touch
  pinMode(PIN_POWER_ON, OUTPUT);
  digitalWrite(PIN_POWER_ON, HIGH);
  touch.begin();

  if (!waitForVescConnection(3000)) {
    log_e("Unable to communicate with VESC. Continuing anyway...");
  }

#ifdef VESC_CONTROLS_LIGHTS
  vescUart.setBrakeLightBrightness(BACK_RUNNING_LIGHT_PERCENT);
  vescUart.setHeadlightState(headlightOnByDefault);
#else
  pinMode(PIN_HEADLIGHT, OUTPUT);
  ledcAttachPin(PIN_REARLIGHT, PWM_CHANNEL);
  ledcSetup(PWM_CHANNEL, PWM_FREQ, PWM_RESOLUTION);
  ledcWrite(PWM_CHANNEL, BACK_RUNNING_LIGHT_PERCENT * 255 / 100);
  digitalWrite(PIN_HEADLIGHT, headlightOnByDefault);
#endif

  changeMode(RevMode::LOCK);
}

// Draws the entire lock screen including the keypad and current PIN display.
// Highlights the key corresponding to the most recent digit in 'pin' (if any).
void drawScreenLock(const String &pin) {
  lockSprite.fillSprite(BACKGROUND_COLOR);
  lockSprite.setTextColor(TFT_WHITE, TFT_BLACK);
  lockSprite.setTextDatum(4);

  int xpos[3] = {3, 58, 113};
  int ypos[4] = {73, 128, 183, 238};
  char keys[4][3] = {
      {'1', '2', '3'}, {'4', '5', '6'}, {'7', '8', '9'}, {' ', '0', 'x'}};

  // Highlight the last pressed key (if any)
  char lastChar = (pin.length() > 0) ? pin.charAt(pin.length() - 1) : '\0';

  for (int i = 0; i < 4; i++) {
    for (int j = 0; j < 3; j++) {
      if (lastChar != '\0' && keys[i][j] == lastChar)
        lockSprite.drawRoundRect(xpos[j], ypos[i], 54, 54, 2, TFT_DARKGREY);
      else
        lockSprite.drawRoundRect(xpos[j], ypos[i], 54, 54, 2, TFT_WHITE);

      lockSprite.drawString(String(keys[i][j]), xpos[j] + 27, ypos[i] + 30, 4);
    }
  }

  // Draw the current PIN entry.
  lockSprite.drawString(pin, 85, 40, 6);

  // Push the sprite to the display.
  lockSprite.pushSprite(0, 0);
}
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

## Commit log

2025-02-08 VESC Dashboard
2025-02-12 fixed crashes occuring when battery voltage is under range (usually when not connected to the rev).
    [config.h, main.cpp]
2025-02-12 added mDNS so ota doesnt need IP. Fixed acceleration when throttle disconnects
    [main.cpp]
2025-02-12 Fixed it so the speed values dont disappear when rolling the scooter backwards. They now clamp at 0.
    [main.cpp]
2025-03-09 changed behavior when throttle isn't configured yet. A few other configs
    [rev_fr_app.xml]
